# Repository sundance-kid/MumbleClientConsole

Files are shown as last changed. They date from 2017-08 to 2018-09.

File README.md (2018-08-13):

# RasPi stage intercom

RasPi stage intercom is a wired and wireless stage intercom system.
It used a headless Raspberry Pi in a 3d printed enclosure as a belt pack,
communicates via wired Ethernet (ability to power the Pi via Power Over Ethernet)
and/or regular Wifi with a local mumble server.
The Mumble client is written in Go.
The project is based on the [talkiepi](https://github.com/dchote/talkiepi/), a walkie talkie style use off the Pi.
Both use GPIO pins for push to talk and LED status.
The Mumble client is a fork of [barnard](https://github.com/layeh/barnard),
which was a great jump off point for me to learn golang and have something that worked relatively quickly.

## 3D printable enclosure

In the stl directory are the stl files for an enclosure for the Raspberry Pi 3 Model B
You will also need a a random USB sound card (to have a microphone input) and a headset + power supply.
(PoE to micro USB extractors exist to only require the one Ethernet cable and no local power supply or power bank)

On the top side are 3 holes for 3mm LEDs in LED-fittings or 5mm LEDs without.
The big hole is for a 19mm illuminated Push-To-Talk button.

I do recomment Dupont connectors and the proper pliers instead of soldering the cables to a single connector.
This way all wires can be removed in case you want to rehouse the electronics into an improved enclosure.

### Generation 1:

Next to it is a 2.5mm TRS connector for an external Push-To-Talk button.
You can use an M6 thread-cutter in the 3D printed plastic to make it screw in perfectly.

### Generation 2: (in development)

On the underside, there is a hole for a round 6 pin mini-DIN socket. 
It is less prone to false signals compare to TRS. 
Each function uses 2 pins.  1+2=GND 3+4=INPUT 5+6=VCC 

There is a square hole in the side for volume +/- controls. 
I used Marquard model 1838.1402  
https://www.marquardt-shop.com/de/produkte/schalter/wippschalter/1830/1838.1402/zeichnungen.html 

Other changes:

There is enough space for a battery-hat on top of the Raspberry. 
The Power over Ethernet -extractor no longer blocks the internal sound card. (unused here but can be used e.g. to output an LTC timecode for cameras.) 
Emergency access to the power-socket is easier. (In case som other power source needs to be connected RIGH NOW.) 
The audio output of the raspberry sound card (that has no microphone input) is accessible. 
The LEDs are labeled. 
The Pins to connect each LED and button to are also labeled on the inside. 

## Installing

Because Github as a file size limit and because I could not keep it updated, I do not offer an  SD-card image. 
When building your own image (Also see the Talkipi readme.md about that. It should be based on at least raspbian-stretch-lite), 
try to keep everything that is device-specific (IP-address, mumble user name, server-ip+password,...) 
in /boot, so it can be accessed from any random computer that can read and write FAT. 
You should have the filesystem read-only by default, so the box can be switched off in any state. 

For the manual installation onto an existing Raspberry Pi, there is an install guide [here](doc/README.md). 
There is a script [INSTALL_INTERCOM](doc/INSTALL_INTERCOM) that does nearly all of these steps.   

In addition you can use GPIO 14+15 (pin 8+10) for volume+/volume- keys. Just copy VOLUMEKEYS_SERVER.txt and INTALL_VOLUME_KEYS into /boot (the root of the FAT-partition) and execute INTALL_VOLUME_KEYS as root. 

## GPIO and LEDs

Pins used: (single row only, so no dual-row connectors are needed)

* 2  = (unused +5V)
* 4  = (unused +5V)
* 6  = GND (for volume)
* 8  = GPIO 14 RESERVED for "Volume+" button
* 10 = GPIO 15 RESERVED for "Volume-" button
* 12 = GPIO 18 = +3.3V for "Online" LED
* 14 = GND (for LEDs)
* 16 = GPIO 23 = +3.3V for "Participants" LED
* 18 = GPIO 24 = +3.3V for "Transmit" LED
* 20 = GND (for PTT)
* 22 = GPIO 25 = Push To Talk (PTT) Button input with pull-up
* 24  = (unused GPIO 8)
* 26 GPIO 7 = +3.3V for a second "Transmit" LED (PTT buttons with build-in LEDs)
* 28  = (unused I2C)
* 30 = GND (for external "Transmit" LED)
* 32 = GPIO 12 = +3.3V for a second "Transmit" LED (PTT buttons with build-in LEDs)

You can edit your pin assignments in `talkiepi.go`
```go
const (
	OnlineLEDPin       uint = 18
	ParticipantsLEDPin uint = 23
	TransmitLEDPin     uint = 24
	ButtonPin          uint = 25
)
```

You can find the pinout for a Raspberry Pi 3 here: https://www.element14.com/community/servlet/JiveServlet/previewBody/73950-102-11-339300/pi3_gpio.png

Here is a basic schematic of how I am currently controlling the LEDs and pushbutton:

schematic GPIO Diagram

A red LED needs 1.8V, so we need 330Ω. 2x 634Ω in parallel are 317Ω. This is close enough. (317Ω * 0.005A = 1.585V; 3.3V - 1.585V = 1.715V)

A green LED needs 2.4V, so we need 220Ω. 2x 440Ω in parallel are obviously perfect.

A yellow LED needs 2.1V, so we need 270Ω. 2x 130Ω in series are close enough.

A blue or white LED needs 3.0V. This needs only a very small resistor (3.3V-3.0V=0.3V => X * 0.005A = 0.3V => X=0.3V/0.005A=60Ω).

Remember, the long side on an LED is +. That's the side that faces VCC=+3.3V on the GPIO pin. The short side faces GND with the resistor in between.

The Push-To-Talk button can also trigger an LED via a chain "3.3V---LED---Led resistor---gpio as input --- button --- GND"

So for a push button with embedded LED we connect:
(+) to 3.3V
(-) via LED-resistor to (N.O.=Normally Open) and to the GPIO pin
(C=Common) to GND

## Pi Zero Fixes
I have compiled libopenal without ARM NEON support so that it works on the Pi Zero. The packages can be found in the [workarounds](/workarounds/). directory of this repo, install the libopenal1 package over your existing libopenal install.

## License

MPL 2.0

## Author

- RasPi-Stage-Intercom - Marcus Wolschon (<Marcus@Wolschon.biz>)
- talkiepi - [Daniel Chote](https://github.com/dchote)
- Barnard,Gumble Author - Tim Cooper (<tim.cooper@layeh.com>)

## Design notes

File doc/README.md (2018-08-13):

# Boot to RasPi stage intercom

This is a simple overview to scratch install RasPi stage intercom (based on [talkiepi](https://github.com/dchote/talkiepi/)) on your Raspberry Pi, and have it start on boot. 
This document assumes that you have raspbian-stretch-lite installed on your SD card, and that the distribution is up to date.
This document also asumes that you have already configured network/wifi connectivity on your Raspberry Pi. 
(hint: add something like " ip=192.168.1.200::192.168.1.1:255.255.255.0:rpi:eth0:on" to cmdline.txt and create an empty file called "ssh" to get started.) 

By default it will run without any arguments, it will autogenerate a username and then connect to the Talkipi mumble server. 
You should change this behavior by appending commandline arguments of e.g. `-server 192.168.1.1:64738`,`-altserver 192.168.1.1:64738` , `-username CAM_A` to the ExecStart line in `/etc/systemd/system/mumble.service` once installed. 

You can set -server and  -altserver to the same address. If server can not be reached, altserver is tried without any delay.
A common setup is for -server to be the Ethernet-address and -altserver to be the address of the same server in Wifi.
-server will always be tried first.

It will also accept arguments for `-password`, `-insecure`, `-certificate` and `-channel`, all defined in `cmd/talkiepi/main.go`, if you run your own mumble server, these will be self explanatory. 

## TL:DR

There is a script [INSTALL_INTERCOM](INSTALL_INTERCOM) that does nearly all of these steps.  
In addition INTALL_VOLUME_KEYS allowy you to also control the ALSA output level of the headphone via 2 buttons on GPIO-pins. 
It assumes a file /boot/INTERCOM_SERVER.txt with the content of /conf/systemd/mumble.service already adapted to your setup (server IP, username, password).

When you are done, see [here](https://learn.adafruit.com/read-only-raspberry-pi/) about a nice script to make the file system read-only (unless a jumper is set at boot time).
GPIO21 (last in the row) looks like a good choice for the R/W jumper.

## Create a user

As root on your Raspberry Pi (`sudo -i`), create a mumble user:
```
adduser --disabled-password --disabled-login --gecos "" mumble
usermod -a -G cdrom,audio,video,plugdev,users,dialout,dip,input,gpio mumble
```

## Install

As root on your Raspberry Pi (`sudo -i`), install golang and other required dependencies, then build talkiepi:
```
apt-get install golang libopenal-dev libopus-dev git

su mumble

mkdir ~/gocode
mkdir ~/bin

export GOPATH=/home/mumble/gocode
export GOBIN=/home/mumble/bin

cd $GOPATH

# formerly: go get github.com/layeh/gopus
go get layeh.com/gopus
go get github.com/dchote/gopus
go get github.com/MarcusWolschon/RasPi_stage_intercom

cd $GOPATH/src/github.com/MarcusWolschon/RasPi_stage_intercom

go build -o /home/mumble/bin/talkiepi cmd/talkiepi/main.go 
```

## Start on boot

As root on your Raspberry Pi (`sudo -i`), copy mumble.service in to place:
```
cp /home/mumble/gocode/src/github.com/MarcusWolschon/RasPi_stage_intercom/conf/systemd/mumble.service /etc/systemd/system/mumble.service

systemctl enable mumble.service
```

## Create a certificate

This is optional, mainly if you want to register your talkiepi against a mumble server and apply ACLs.
```
su mumble
cd ~

openssl genrsa -aes256 -out key.pem
```

Enter a simple passphrase, its ok, we will remove it shortly...

```
openssl req -new -x509 -key key.pem -out cert.pem -days 1095
```

Enter your passphrase again, and fill out the certificate info as much as you like, its not really that important if you're just hacking around with this.

```
openssl rsa -in key.pem -out nopasskey.pem
```

Enter your password for the last time.

```
cat nopasskey.pem cert.pem > mumble.pem
```

Now as root again (`sudo -i`), edit `/etc/systemd/system/mumble.service` appending `-username USERNAME_TO_REGISTER -certificate /home/mumble/mumble.pem` at the end of `ExecStart = /home/mumble/bin/talkiepi`

Run `systemctl daemon-reload` and then `service mumble restart` and you should be set with a tls certificate!

For debugging audio you can start /home/mumble/bin/talkiepi with export ALSOFT_LOGLEVEL=4 set; 

## Install the USB soundcard

Because the raspberry pi does not come with a microphone port, we use a common USB soundcard to do that job.
You will need to change the default system sound device.
As root on your Raspberry Pi (`sudo -i`), find your device by running `aplay -l`, take note of the index of the device (likely 1) and then edit the alsa config (`/usr/share/alsa/alsa.conf`), changing the following:
```
defaults.ctl.card 1
defaults.pcm.card 1
```
_1 being the index of your device_

If your headset is too quiet, you can adjust the volume using amixer as such:
```
amixer -c 1 set Headphone 60%
```
or 
```
amixer -c 1 set Speaker 60%
```
_1 being the index of your device_

I will be adding volume control settings in an upcoming push.

## install mumble server

First we need to get a mumble server. e.g. from https://wiki.natenom.de/mumble/mumble-herunterladen

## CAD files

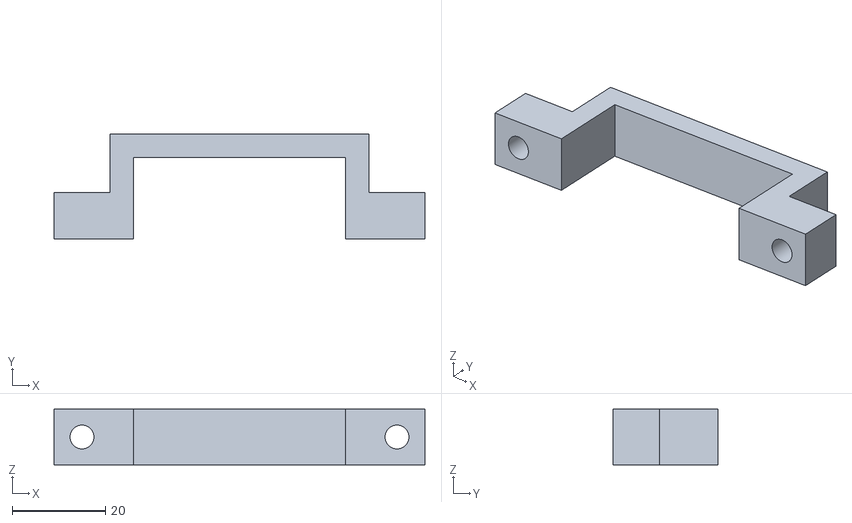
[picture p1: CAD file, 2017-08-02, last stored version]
cad/hdmi_extender/HDMI_Extender_Brace_small_PRT.stl
79.5 x 22.5 x 12.0

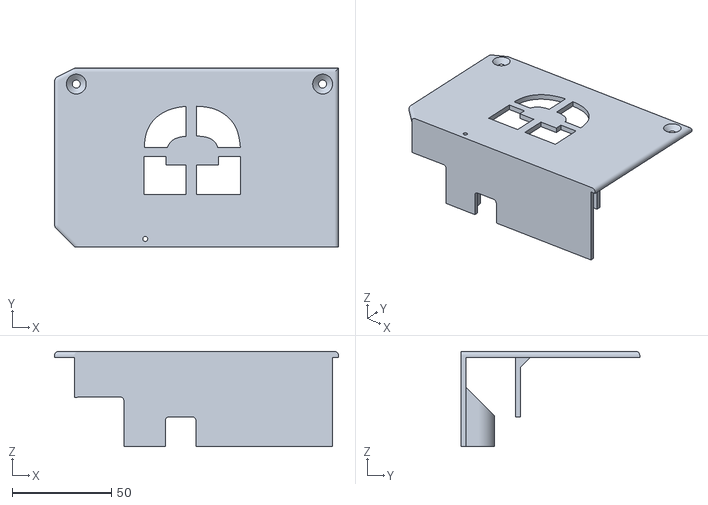
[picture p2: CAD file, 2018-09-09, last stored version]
stl/2018-08-17_Beltpack_upper_camD gen2.stl
143.1 x 90.0 x 48.0

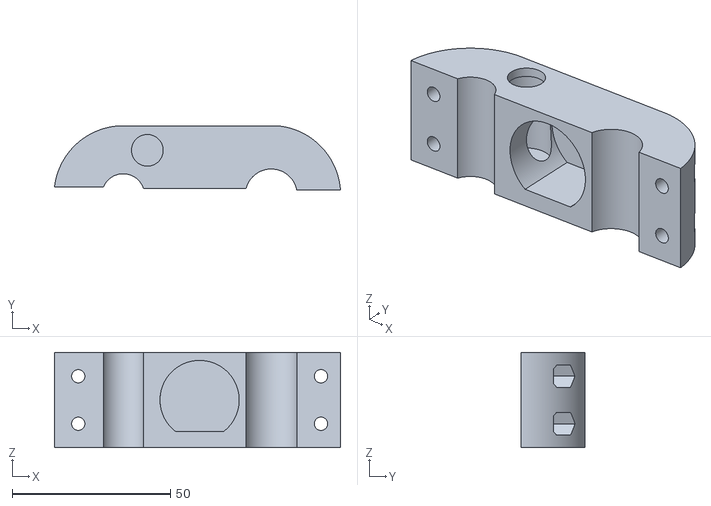
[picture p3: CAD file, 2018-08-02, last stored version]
stl/external_PushToTalk_Button/externalPTT_bottom.stl
90.3 x 20.3 x 30.0

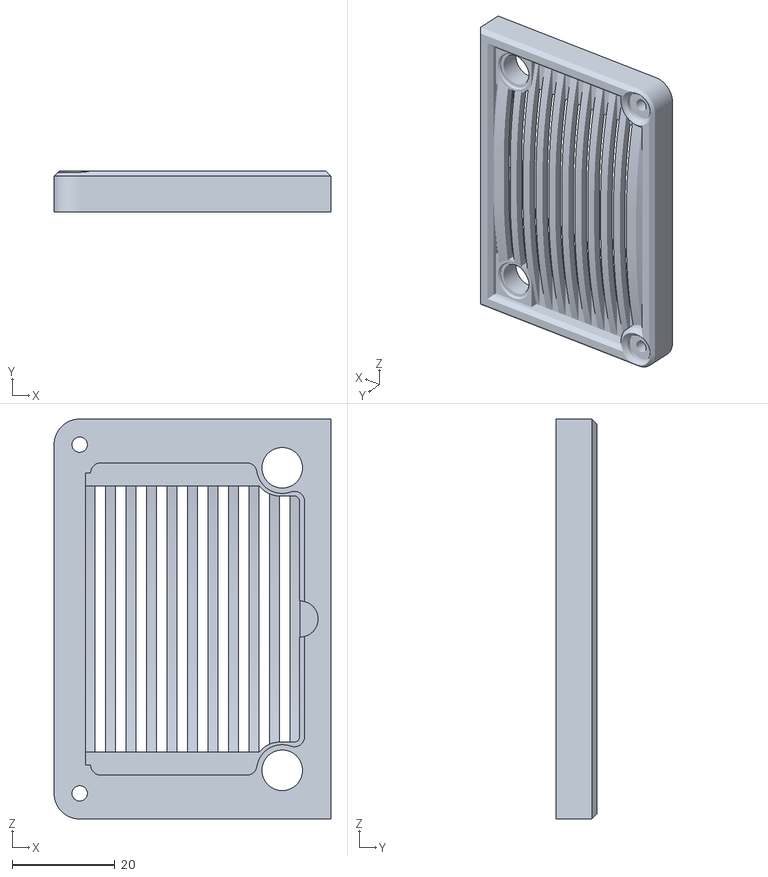
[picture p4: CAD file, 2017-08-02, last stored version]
stl/walkietalkie/speaker_cover.stl
54.0 x 8.00 x 78.0

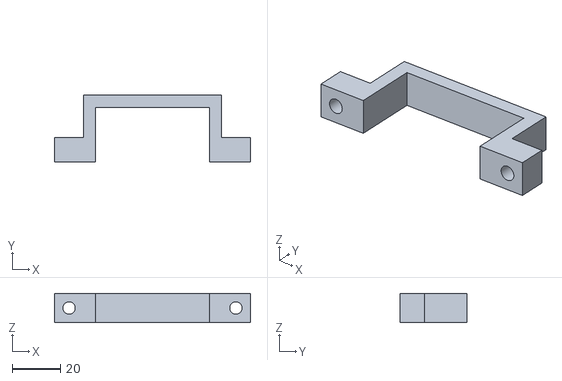
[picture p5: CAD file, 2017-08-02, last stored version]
cad/hdmi_extender/hdmi_extender_brace.stl
81.0 x 27.5 x 12.0

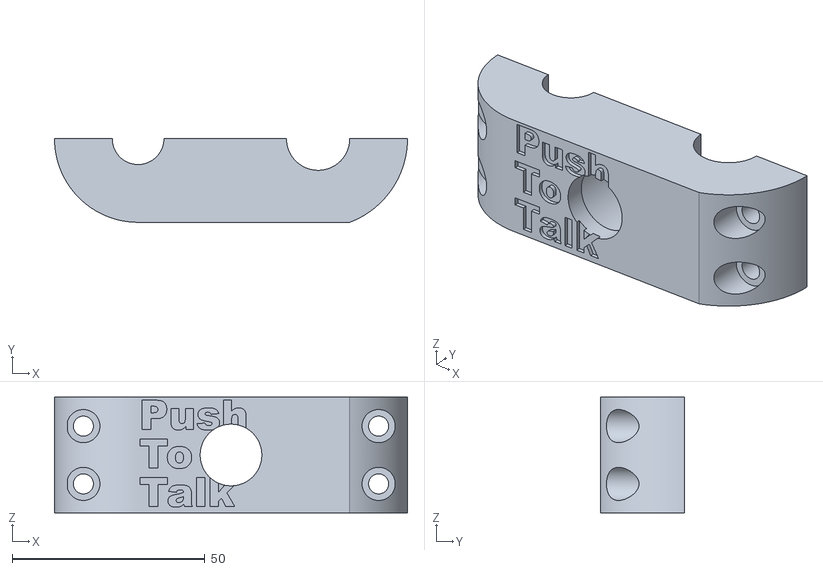
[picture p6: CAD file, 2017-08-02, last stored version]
stl/external_PushToTalk_Button/externalPTT_top.stl
91.6 x 21.7 x 30.0

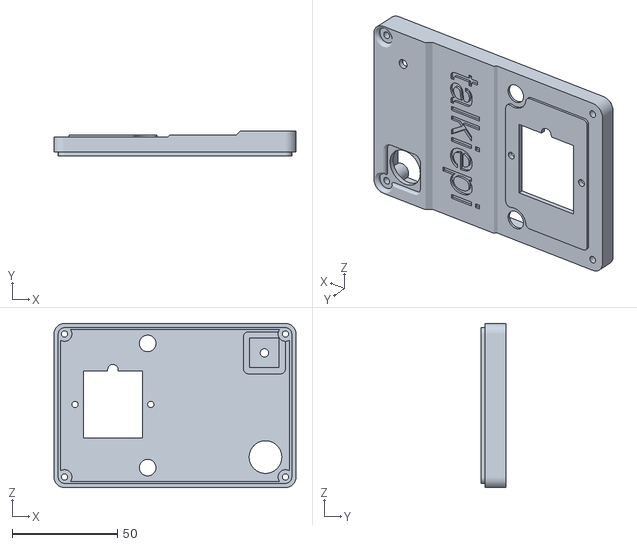
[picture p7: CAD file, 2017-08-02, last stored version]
stl/walkietalkie/case_top.stl
115.0 x 12.0 x 78.0

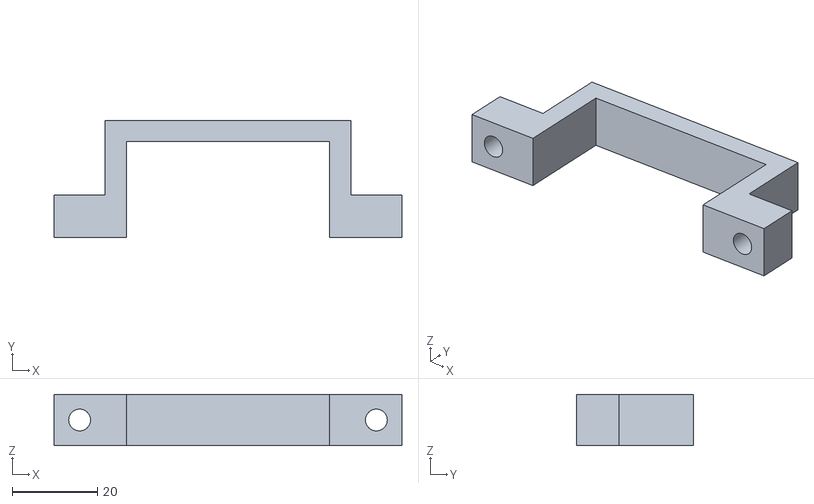
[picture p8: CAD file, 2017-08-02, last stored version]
cad/hdmi_extender/HDMI_Extender_Brace_PRT.stl
81.5 x 27.5 x 12.0

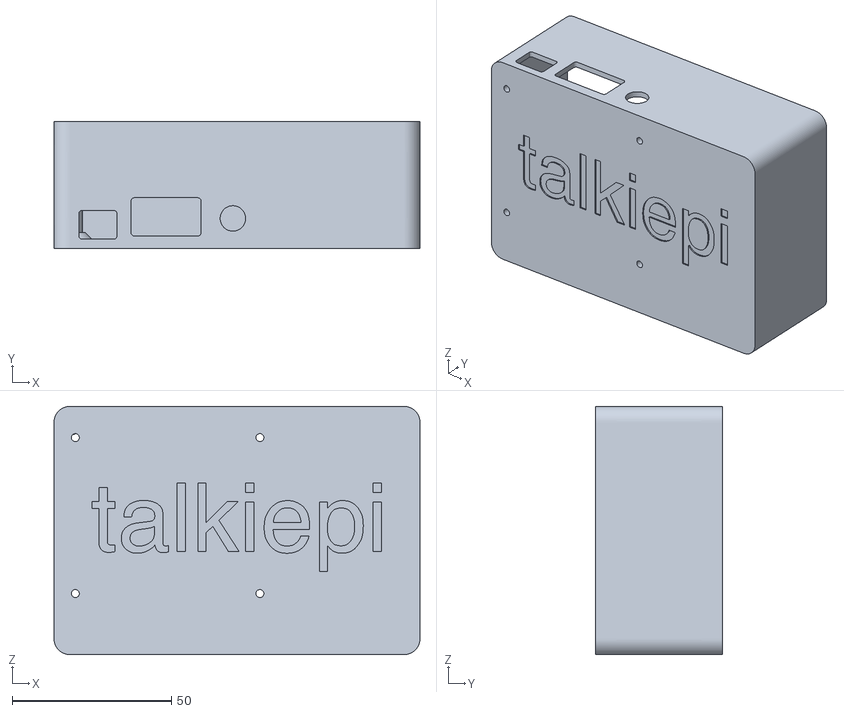
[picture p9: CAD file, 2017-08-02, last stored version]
stl/walkietalkie/case_bottom.stl
115.0 x 40.0 x 78.0

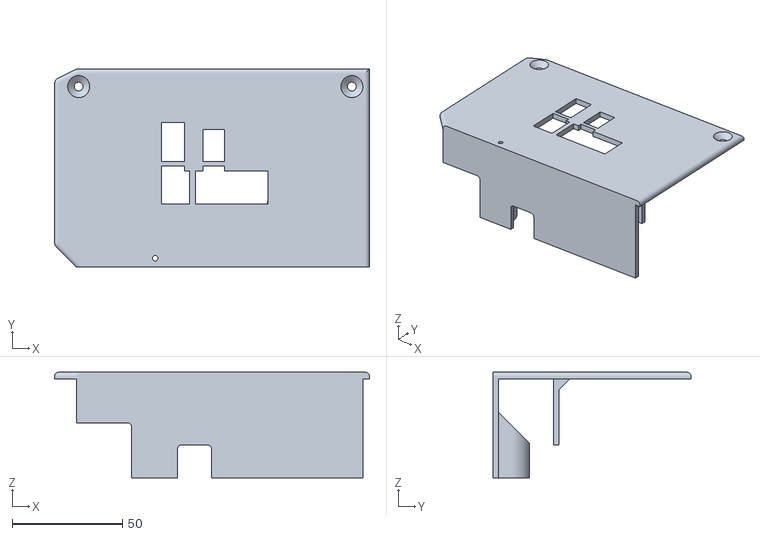
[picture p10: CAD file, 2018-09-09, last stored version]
stl/2018-08-17_Beltpack_upper_camF gen2.stl
143.1 x 90.0 x 48.0

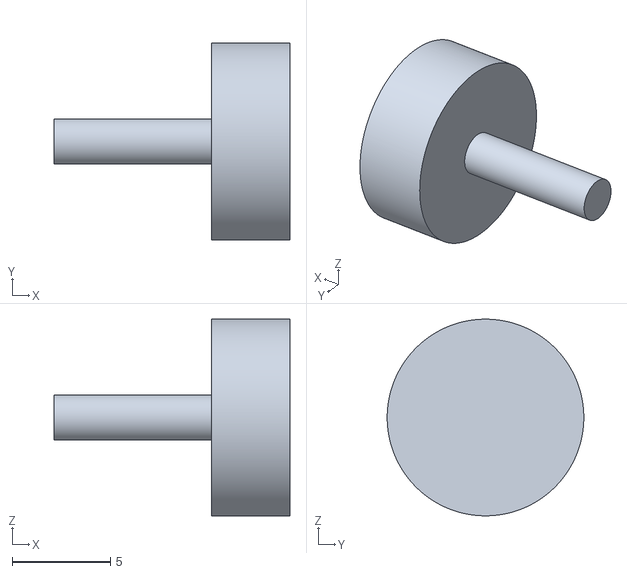
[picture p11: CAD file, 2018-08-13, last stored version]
stl/2018-08-12_Beltpack_lower gen2_USP-PowerButton.stl
12.0 x 10.0 x 10.0

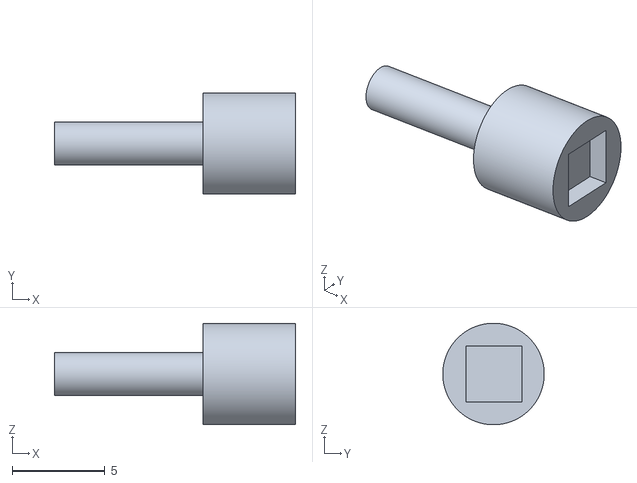
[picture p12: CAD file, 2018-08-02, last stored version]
stl/Beltpack_lower gen2_USP-PowerButton.stl
13.0 x 5.47 x 5.47

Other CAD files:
stl/2018-08-17_Beltpack_upper_camC gen2.stl
stl/2018-08-17_Beltpack_upper_camA gen2.stl
stl/2018-08-17_Beltpack_upper_camE gen2.stl
stl/2018-08-12_Beltpack_upper_camD gen2.stl
stl/2018-08-10_Beltpack_upper_camA gen2.stl
stl/2018-08-12_Beltpack_upper_camE gen2.stl
stl/Beltpack_upper_camE gen2.stl

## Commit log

2017-08-02 added beltpack CAD files
2017-08-02 added external Push-To-Talk button holder
2017-08-02 updated STL exports
    [case_bottom.stl, case_top.stl, externalPTT_bottom.stl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]
2017-08-02 added brace for HDMI over Cat5e - extenders
    [HDMI_Extender_Brace_PRT.stl, HDMI_Extender_Brace_small_PRT.stl, hdmi_extender_brace.stl]
2017-08-02 additional READMEs and a brace for an ethernet switch
2018-08-02 Updated installation instructions. Updated dependencies. Experimental generation II beltpack.
    [Beltpack_lower gen2_USP-PowerButton.stl, Beltpack_upper_camE gen2.stl, externalPTT_bottom.stl]
2018-08-02 support for an illuminated internal + an external Push To Talk (PTT) button
2018-08-13 minor updates
    [2018-08-10_Beltpack_upper_camA gen2.stl, 2018-08-12_Beltpack_lower gen2_USP-PowerButton.stl, 2018-08-12_Beltpack_upper_camD gen2.stl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]
2018-09-09 Added server for volume-keys. STL exports of beltpack with various letters
    [2018-08-17_Beltpack_upper_camA gen2.stl, 2018-08-17_Beltpack_upper_camC gen2.stl, 2018-08-17_Beltpack_upper_camD gen2.stl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]
